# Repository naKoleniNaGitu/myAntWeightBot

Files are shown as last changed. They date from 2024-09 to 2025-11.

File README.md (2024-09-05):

# myAntWeightBot

## Sources

### Controler 
I decided to go with ESP32-S3 develoment module for control flexibility and BT connectivity.

* [waveshare.com product esp32-s3-zero.htm](https://www.waveshare.com/product/mcu-tools/development-boards/esp32/esp32-s3-zero.htm)
* [ESP32 S3 zero wiki](https://www.waveshare.com/wiki/ESP32-S3-Zero)

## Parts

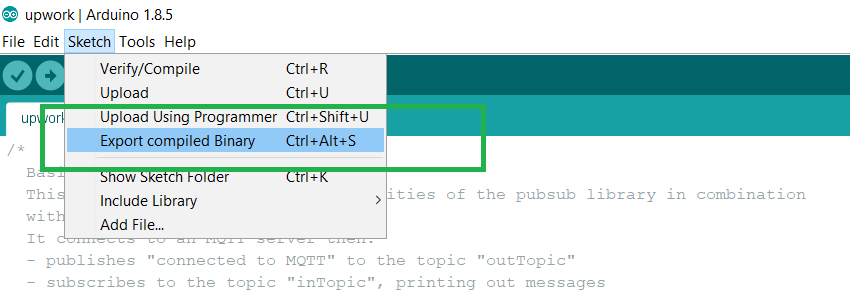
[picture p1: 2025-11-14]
platformio_projects/myAntWeightBot_v3/components/arduino/docs/_static/ota_export_to_binary.png

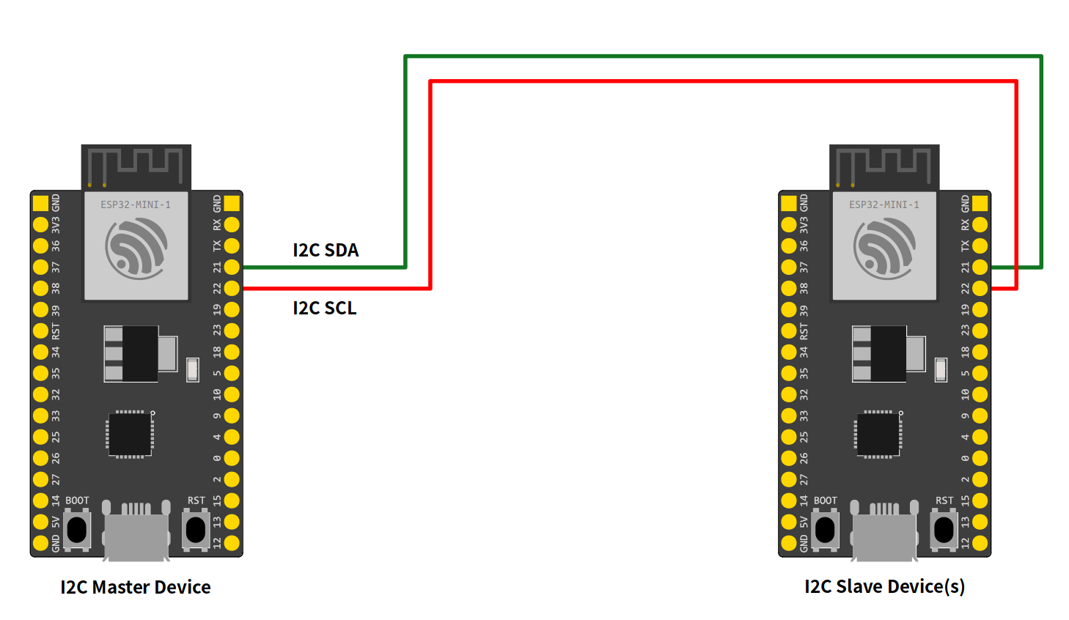
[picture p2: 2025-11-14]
platformio_projects/myAntWeightBot_v3/components/arduino/docs/_static/arduino_i2c_slave.png

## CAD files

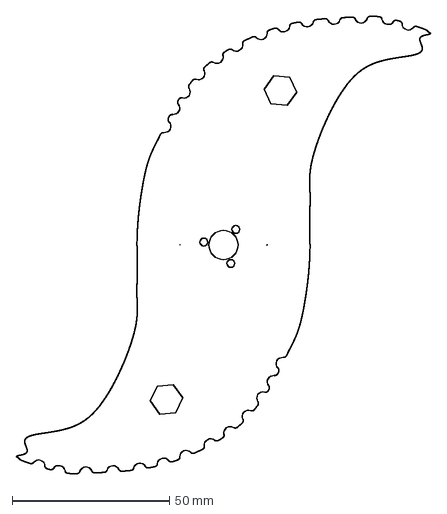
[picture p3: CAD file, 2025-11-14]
CNC blade.dxf
131.6 x 145.4 mm

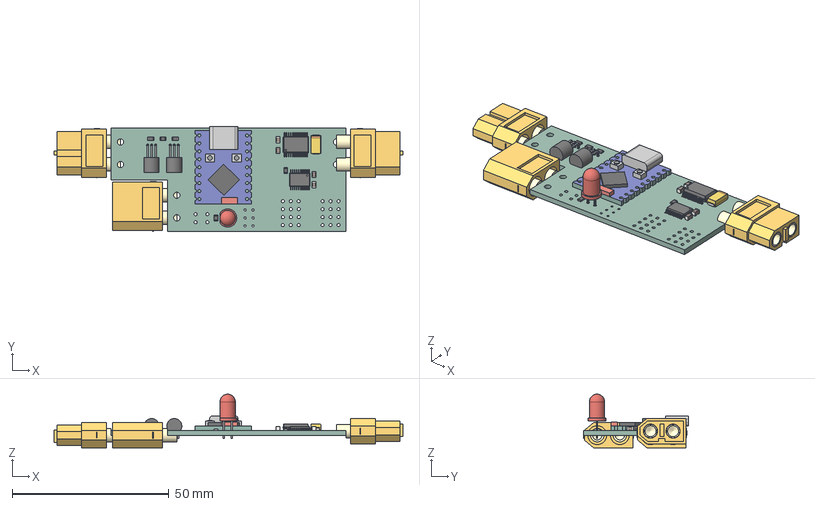
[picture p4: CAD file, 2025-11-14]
HW design/myAntWeightBot/myAntWeightBot.step
111.4 x 33.6 x 17.2 mm
R_0805_2012Metric x 5
LED_D5.0mm
AMASS_XT60-F_1x02_P7.2mm_Vertical v2 x 2
CP_EIA_6032_20_AVX_F
C_0805_2012Metric x 4
TO-92_Inline_W4.0mm_Horizontal_FlatSideDown x 2
TSSOP_20_44x65mm_P065mm
ESP32-S3-Zero v2
SSOP_24_53x82mm_P065mm
AMASS_XT60-M_1x02_P7.2mm_Vertical v2
myAntWeightBot_PCB

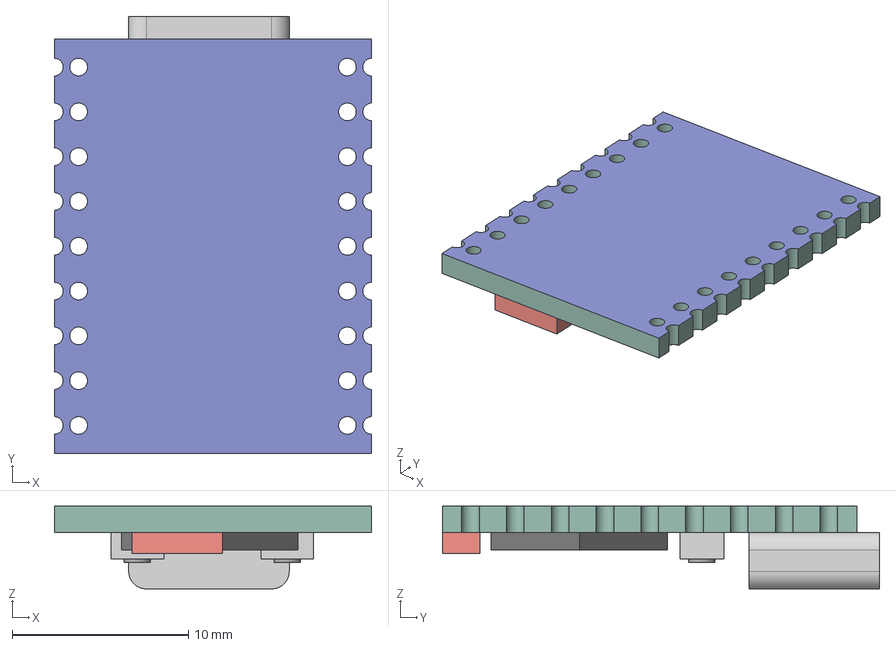
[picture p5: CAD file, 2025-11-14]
STL/ESP32-S3-Zero v2.step
18.0 x 24.8 x 4.70 mm

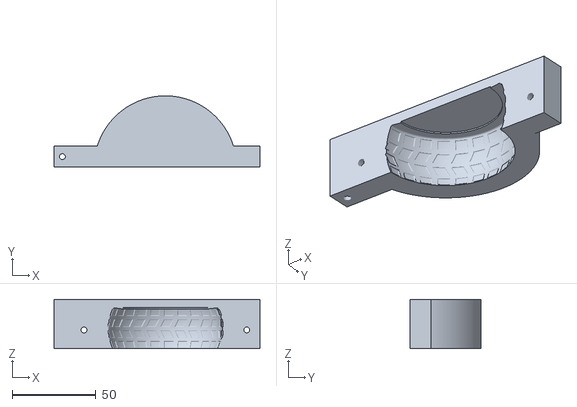
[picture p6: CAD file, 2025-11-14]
STL/wheel mold/wheel mold v1 - side L.stl
122.8 x 42.5 x 29.5

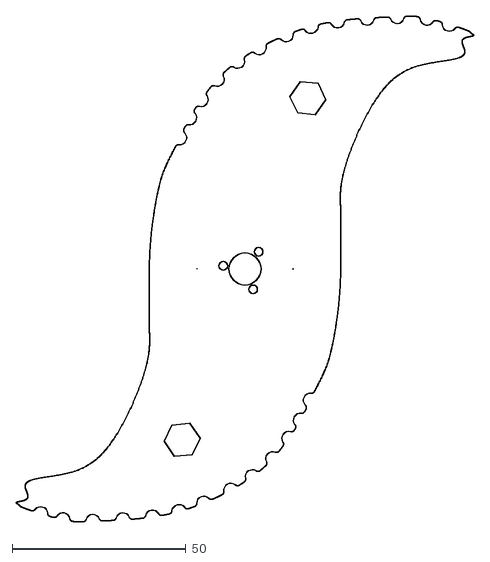
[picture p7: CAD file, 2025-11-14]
CNC blade v10.dxf
131.6 x 145.4

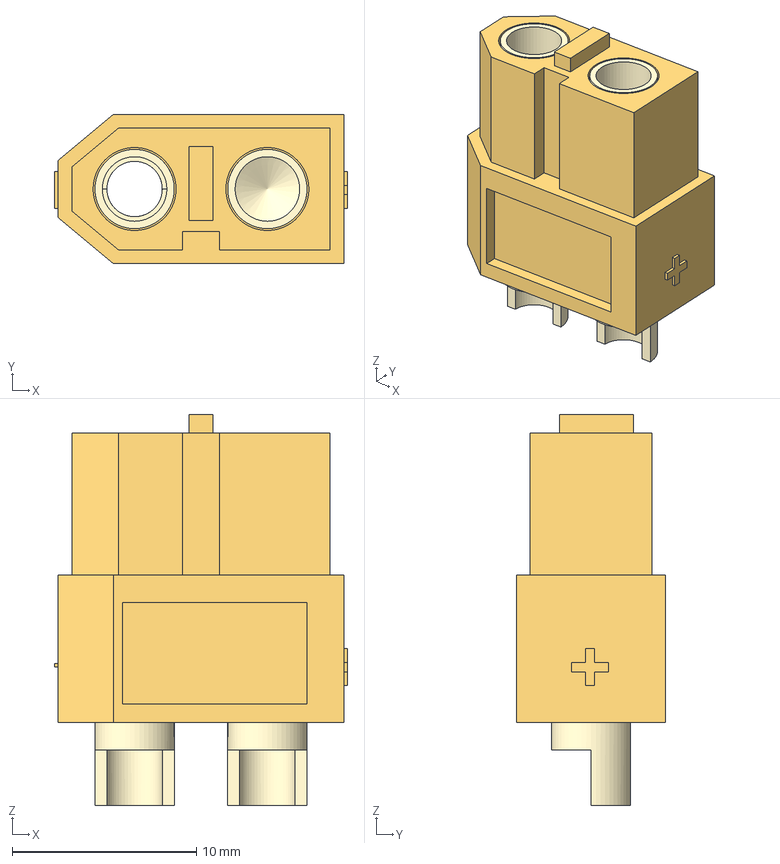
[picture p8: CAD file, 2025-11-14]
STL/AMASS_XT60-F_1x02_P7.2mm_Vertical v2.step
15.9 x 8.10 x 21.2 mm

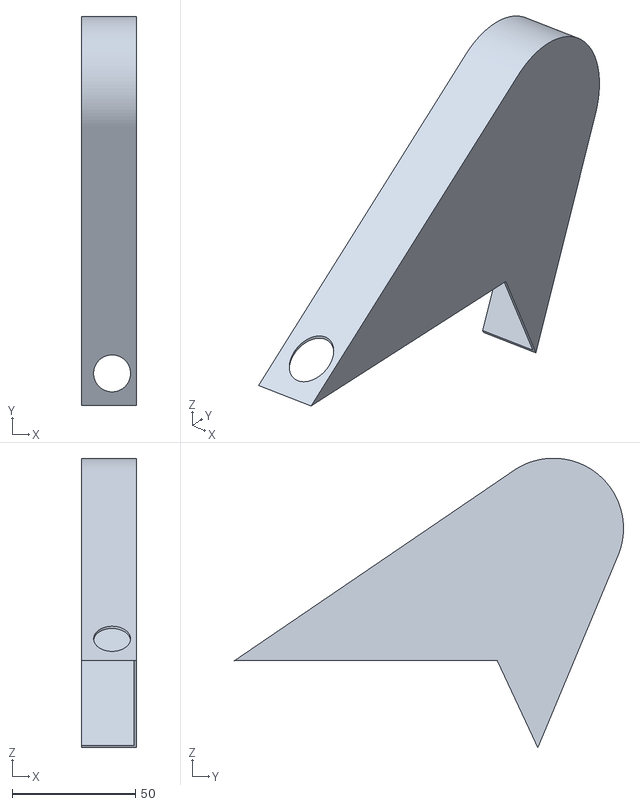
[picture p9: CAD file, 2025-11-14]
STL/insert right v 27.stl
22.5 x 158.0 x 117.6

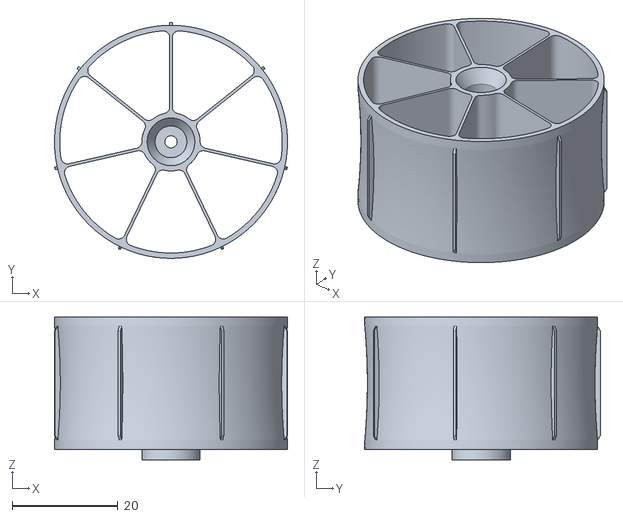
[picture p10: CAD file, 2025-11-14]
STL/strawberryBot & ufoBot/Wheel D50x25 v10.stl
44.0 x 44.5 x 27.0

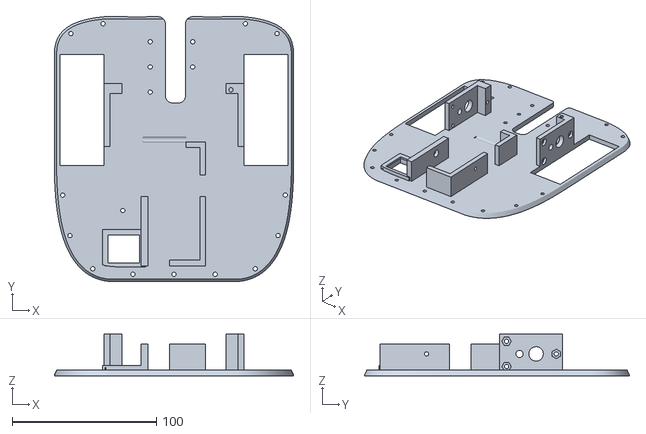
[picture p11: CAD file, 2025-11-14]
STL/BasePlate v28.stl
166.1 x 183.9 x 29.0

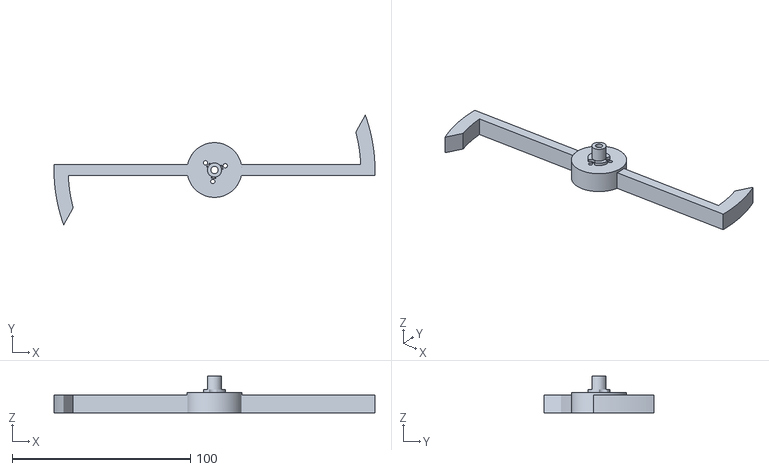
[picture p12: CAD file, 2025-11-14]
STL/strawberryBot & ufoBot/strawberryWeapon v3.stl
180.0 x 61.6 x 20.5

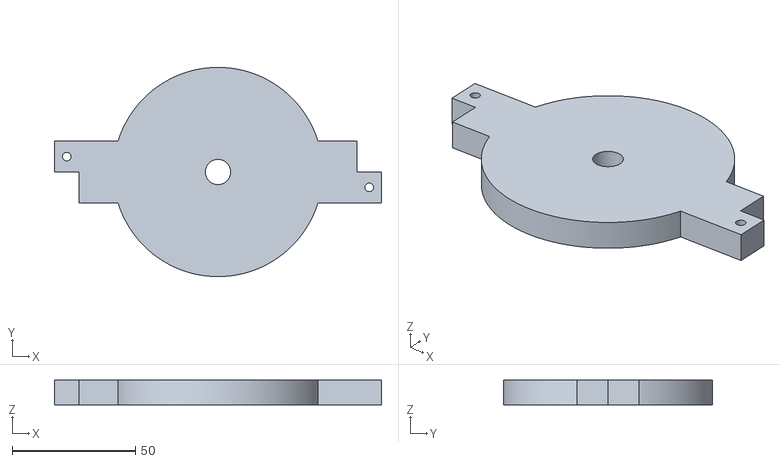
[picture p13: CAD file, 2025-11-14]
STL/wheel mold/wheel mold v3 - lid.stl
132.8 x 85.0 x 10.0

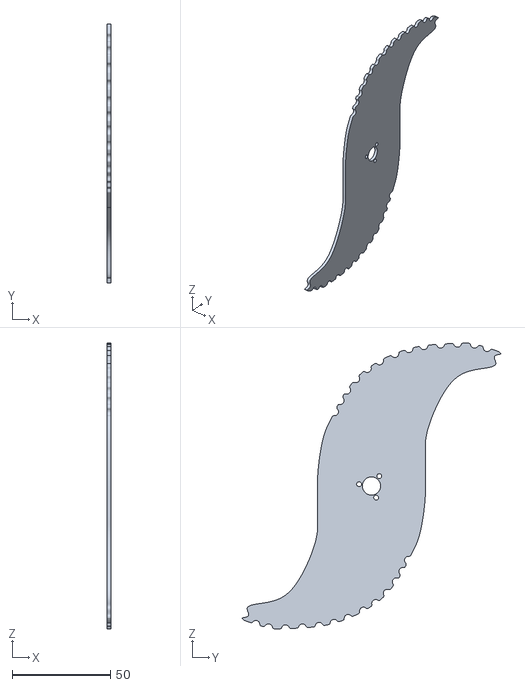
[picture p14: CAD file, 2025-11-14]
STL/blade v15.stl
2.00 x 131.6 x 145.4

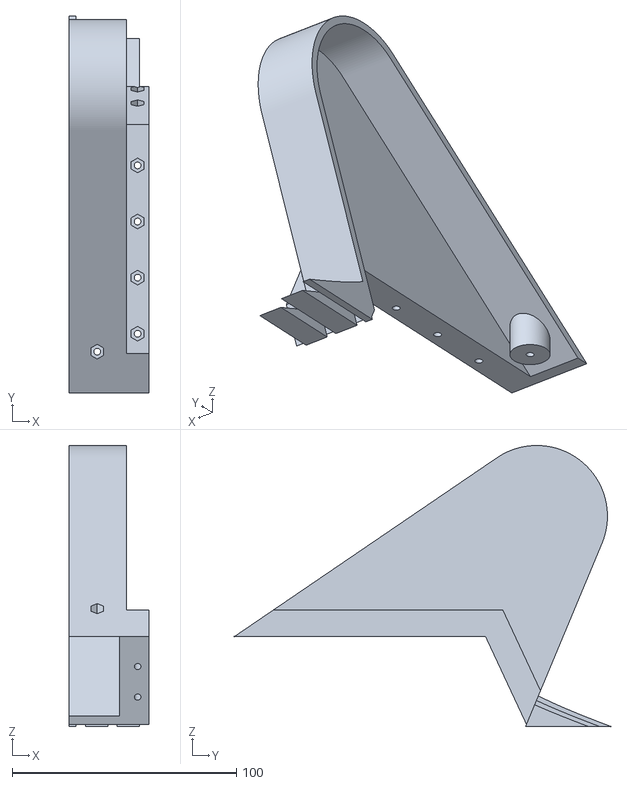
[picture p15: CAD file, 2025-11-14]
STL/ArmCover v 25.stl
35.5 x 167.9 x 125.2

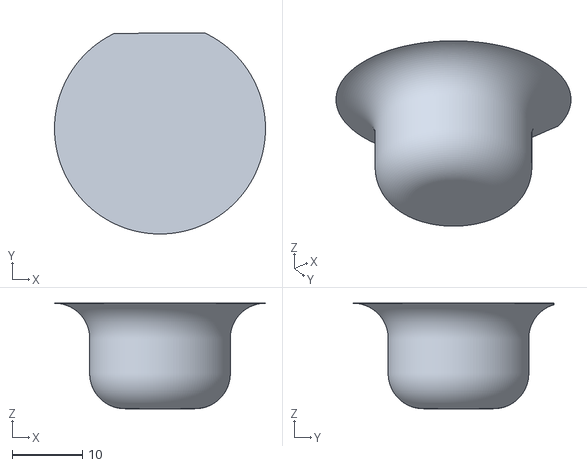
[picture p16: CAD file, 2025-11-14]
STL/SlidingPad 2 v15.stl
30.0 x 28.6 x 15.0

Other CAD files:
STL/wheel mold/wheel mold v1 - side R.stl
STL/BearingHolder v21.stl
STL/SlidingPad 3 v15.stl
STL/BasePlate.stl
CNC blade.dwg
STL/AMASS_XT60-M_1x02_P7.2mm_Vertical v2.step
STL/ArmCover Left v29.stl
STL/ArmCover Right v29.stl
STL/Armor v29.stl
STL/Armor v32.stl
STL/BasePlate v11.stl
STL/BasePlate v13.stl
STL/BasePlate v15.stl
STL/BladeHolder v11.stl
STL/BladeHolder v15.stl
STL/Shell v30.stl
STL/Shell v31.stl
STL/Shim v31.stl
STL/SlidingPad 1 v11.stl
STL/SlidingPad 1 v15.stl
STL/SlidingPad 2 v11.stl
STL/SlidingPad 3 v11.stl
STL/blade v11.stl
STL/strawberryBot & ufoBot/Wheel D50x25 v7.stl
STL/strawberryBot & ufoBot/Wheel D50x25 v8.stl
STL/strawberryBot & ufoBot/strawberryWeapon v2.stl
STL/wheel mold/wheel mold v1 - lid.stl

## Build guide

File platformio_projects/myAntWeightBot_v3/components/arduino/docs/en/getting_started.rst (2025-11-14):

###############
Getting Started
###############

About Arduino ESP32
-------------------

Welcome to the Arduino ESP32 support documentation! Here you will find important information on how to use the project.

First Things First
------------------

.. note::
    Before continuing, we must be clear that this project is supported by `Espressif Systems`_ and the community.
    Everyone is more than welcome to contribute back to this project.

ESP32 is a single 2.4 GHz Wi-Fi-and-Bluetooth SoC (System On a Chip) designed by `Espressif Systems`_.

ESP32 is designed for mobile, wearable electronics, and Internet-of-Things (IoT) applications. It features all the state-of-the-art characteristics
of low-power chips, including fine-grained clock gating, multiple power modes,and dynamic power scaling. For instance, in a low-power IoT sensor
hub application scenario, ESP32 is woken-up periodically and only when a specified condition is detected. Low-duty cycle is used to minimize the
amount of energy that the chip expends.

The output of the power amplifier is also adjustable, thus contributing to an optimal trade-off between communication range, data rate and
power consumption.

The ESP32 series is available as a chip or module.

.. _supported_socs:

Supported SoC's
---------------

Here are the ESP32 series supported by the Arduino-ESP32 project:

========== ====== =========== =================================
SoC        Stable Development Datasheet
========== ====== =========== =================================
ESP32      Yes    Yes         `ESP32`_
ESP32-C3   Yes    Yes         `ESP32-C3`_
ESP32-C6   Yes    Yes         `ESP32-C6`_
ESP32-H2   Yes    Yes         `ESP32-H2`_
ESP32-P4   Yes    Yes         `ESP32-P4`_
ESP32-S2   Yes    Yes         `ESP32-S2`_
ESP32-S3   Yes    Yes         `ESP32-S3`_
========== ====== =========== =================================

.. note::
    ESP32-C2 is also supported by Arduino-ESP32 but requires using Arduino as an ESP-IDF component or rebuilding the static libraries.
    For more information, see the `Arduino as an ESP-IDF component documentation <esp-idf_component.html>`_ or the
    `Lib Builder documentation <lib_builder.html>`_, respectively.

See `Boards <boards/boards.html>`_ for more details about ESP32 development boards.

Arduino Core Reference
----------------------

This documentation is built on the ESP32 and we are not going to cover the common Arduino API. To see the Arduino reference documentation,
please consider reading the official documentation.

Arduino Official Documentation: `Arduino Reference`_.

Supported Operating Systems
---------------------------

+-------------------+-------------------+-------------------+
|     |       |       |
+-------------------+-------------------+-------------------+
| Windows           | Linux             | macOS             |
+-------------------+-------------------+-------------------+





Supported IDEs
---------------------------

Here is the list of supported IDE for Arduino ESP32 support integration.

+-------------------+
|     |
+-------------------+
| Arduino IDE       |
+-------------------+



See `Installing Guides <installing.html>`_ for more details on how to install the Arduino ESP32 support.

Support
-------

This is an open project and it's supported by the community. Fell free to ask for help in one of the community channels.

Community
---------

The Arduino community is huge! You can find a lot of useful content on the Internet.
Here are some community channels where you may find information and ask for some help, if needed.

- `ESP32 Forum`_: Official Espressif Forum.
- `ESP32 Forum - Arduino`_: Official Espressif Forum for Arduino related discussions.
- `ESP32 Forum - Hardware`_: Official Espressif Forum for Hardware related discussions.
- `Espressif Developer Portal`_: Official Espressif Developer Portal with tutorials, examples, workshops, and more.
- `Arduino Core for Espressif (Discord)`_: Official Espressif Discord channel for the Arduino Core.
- `Espressif MCUs (Discord)`_
- `ESP32 on Reddit`_

Issues Reporting
----------------

Before opening a new issue, please read this:

Be sure to search for a similar reported issue. This avoids duplicating or creating noise in the GitHub Issues reporting.
We also have the troubleshooting guide to save your time on the most common issues reported by users.

For more details about creating new Issue, see the `Issue Template <https://github.com/espressif/arduino-esp32/blob/master/.github/ISSUE_TEMPLATE/Issue-report.yml>`_.

If you have any new idea, see the `Feature request Template <https://github.com/espressif/arduino-esp32/blob/master/.github/ISSUE_TEMPLATE/Feature-request.yml>`_.

First Steps
-----------

Here are the first steps to get the Arduino ESP32 support running.

To install Arduino-ESP32, please see the dedicated section on the Installation guide. We recommend you install it using the boards manager.

.. toctree::
    :maxdepth: 2

    How to Install <installing>
    Development Boards <boards/boards>

Examples
--------

After installing the toolchain into your environment, you will be able to see all the dedicated examples for the ESP32. These examples are located
in the examples menu or inside each library folder.

    https://github.com/espressif/arduino-esp32/tree/master/libraries

There is also a `list of examples <https://techtutorialsx.com/category/esp32/>`_ managed outside of Espressif, so check them out.

.. include:: common/datasheet.inc

Resources
---------

.. _Espressif Systems: https://www.espressif.com
.. _Espressif Product Selector: https://products.espressif.com/
.. _Espressif Developer Portal: https://developer.espressif.com/
.. _Arduino.cc: https://www.arduino.cc/en/Main/Software
.. _Arduino Reference: https://www.arduino.cc/reference/en/
.. _ESP32 Forum: https://esp32.com
.. _ESP32 Forum - Arduino: https://esp32.com/viewforum.php?f=19
.. _ESP32 Forum - Hardware: https://esp32.com/viewforum.php?f=12
.. _Arduino Core for Espressif (Discord): https://discord.gg/8xY6e9crwv
.. _Adafruit (Discord): https://discord.gg/adafruit
.. _Espressif MCUs (Discord): https://discord.com/invite/XqnZPbF
.. _ESP32 on Reddit: https://www.reddit.com/r/esp32

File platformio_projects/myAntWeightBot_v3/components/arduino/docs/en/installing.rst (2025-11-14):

##########
Installing
##########

This guide will show how to install the Arduino-ESP32 support.

Before Installing
-----------------

We recommend you install the support using your favorite IDE, but other options are available depending on your operating system.
To install Arduino-ESP32 support, you can use one of the following options.

.. note::
   Users in China might have troubles with connection and download speeds using GitHub. Please use our Jihulab mirror as the repository source:

   ``https://jihulab.com/esp-mirror/espressif/arduino-esp32.git``

Installing using Arduino IDE
----------------------------



This is the way to install Arduino-ESP32 directly from the Arduino IDE.

.. note::
   For overview of SoC's support, take a look on `Supported Soc's table <https://docs.espressif.com/projects/arduino-esp32/en/latest/getting_started.html#supported-soc-s>`_ where you can find if the particular chip is under stable or development release.

- Stable release link::

   https://espressif.github.io/arduino-esp32/package_esp32_index.json

- Development release link::

   https://espressif.github.io/arduino-esp32/package_esp32_dev_index.json

Users in China might have troubles with connection and download speeds using the links above. Please use our Jihulab mirror:

- Stable release link::

   https://jihulab.com/esp-mirror/espressif/arduino-esp32/-/raw/gh-pages/package_esp32_index_cn.json

- Development release link::

   https://jihulab.com/esp-mirror/espressif/arduino-esp32/-/raw/gh-pages/package_esp32_dev_index_cn.json

.. note::
   Starting with the Arduino IDE version 1.6.4, Arduino allows installation of third-party platform
   packages using Boards Manager. We have packages available for Windows, macOS, and Linux.

To start the installation process using the Boards Manager, follow these steps:

-  Install the current upstream Arduino IDE at the 1.8 level or later. The current version is at the `arduino.cc`_ website.

-  Start Arduino and open the Preferences window.



-  Enter one of the release links above into *Additional Board Manager URLs* field. You can add multiple URLs, separating them with commas.



-  Open Boards Manager from Tools > Board menu and install *esp32* platform (and do not forget to select your ESP32 board from Tools > Board menu after installation).
   Users in China must select the package version with the "-cn" suffix and perform updates manually.
   Automatic updates are not supported in this region, as they target the default package without the "-cn" suffix, resulting in download failures.



- Restart Arduino IDE.

Windows (manual installation)
-----------------------------

.. warning:: Arduino ESP32 core v2.x.x cannot be used on Windows 8.x x86 (32 bits), Windows 7 or earlier. The Windows 32 bits OS is no longer supported by this toolchain.

   The Arduino ESP32 v1.0.6 still works on WIN32. You might want to install python 3.8.x because it is the latest release supported by Windows 7.

Steps to install Arduino ESP32 support on Windows:

**Step 1**

1. Download and install the latest Arduino IDE ``Windows Installer`` from [arduino.cc](https://www.arduino.cc/en/Main/Software)
2. Download and install Git from [git-scm.com](https://git-scm.com/download/win)
3. Start ``Git GUI`` and do the following steps:

- Select ``Clone Existing Repository``



- Select source and destination
   - Sketchbook Directory: Usually ``C:/Users/[YOUR_USER_NAME]/Documents/Arduino`` and is listed underneath the "Sketchbook location" in Arduino preferences.
   - Source Location: ``https://github.com/espressif/arduino-esp32.git``
   - Target Directory: ``[ARDUINO_SKETCHBOOK_DIR]/hardware/espressif/esp32``
   - Click ``Clone`` to start cloning the repository

**Step 2**



**Step 3**



- open a `Git Bash` session pointing to ``[ARDUINO_SKETCHBOOK_DIR]/hardware/espressif/esp32`` and execute ```git submodule update --init --recursive```
- Open ``[ARDUINO_SKETCHBOOK_DIR]/hardware/espressif/esp32/tools`` and double-click ``get.exe``

**Step 4**



- When ```get.exe``` finishes, you should see the following files in the directory

**Step 5**



1. Plug your ESP32 board and wait for the drivers to install (or install manually any that might be required)
2. Start Arduino IDE
3. Select your board in ``Tools > Board`` menu
4. Select the COM port that the board is attached to
5. Compile and upload (You might need to hold the boot button while uploading)



How to update to the latest code
********************************

1. Start ``Git GUI`` and you should see the repository under ``Open Recent Repository``. Click on it!



1. From menu ``Remote`` select ``Fetch from`` > ``origin``



1. Wait for git to pull any changes and close ``Git GUI``
2. Open ``[ARDUINO_SKETCHBOOK_DIR]/hardware/espressif/esp32/tools`` and double-click ``get.exe``



Linux
-----



Debian/Ubuntu
*************

- Install latest Arduino IDE from `arduino.cc`_.

- Open Terminal and execute the following command (copy -> paste and hit enter):

.. code-block:: bash

   sudo usermod -a -G dialout $USER && \
   sudo apt-get install git && \
   wget https://bootstrap.pypa.io/get-pip.py && \
   sudo python3 get-pip.py && \
   sudo pip3 install pyserial && \
   mkdir -p ~/Arduino/hardware/espressif && \
   cd ~/Arduino/hardware/espressif && \
   git clone https://github.com/espressif/arduino-esp32.git esp32 && \
   cd esp32/tools && \
   python3 get.py

- Restart Arduino IDE.

- If you have Arduino installed to ~/, modify the installation as follows, beginning at `mkdir -p ~/Arduino/hardware`:

.. code-block:: bash

   cd ~/Arduino/hardware
   mkdir -p espressif && \
   cd espressif && \
   git clone https://github.com/espressif/arduino-esp32.git esp32 && \
   cd esp32/tools && \
   python3 get.py

Fedora
******

- Install the latest Arduino IDE from `arduino.cc`_.

.. note::
   Command ``$ sudo dnf -y install arduino`` will most likely install an older release.

- Open Terminal and execute the following command (copy -> paste and hit enter):

.. code-block:: bash

   sudo usermod -a -G dialout $USER && \
   sudo dnf install git python3-pip python3-pyserial && \
   mkdir -p ~/Arduino/hardware/espressif && \
   cd ~/Arduino/hardware/espressif && \
   git clone https://github.com/espressif/arduino-esp32.git esp32 && \
   cd esp32/tools && \
   python get.py

- Restart Arduino IDE.

openSUSE
********

- Install the latest Arduino IDE from `arduino.cc`_.

- Open Terminal and execute the following command (copy -> paste and hit enter):

.. code-block:: bash

   sudo usermod -a -G dialout $USER && \
   if [ `python --version 2>&1 | grep '2.7' | wc -l` = "1" ]; then \
   sudo zypper install git python-pip python-pyserial; \
   else \
   sudo zypper install git python3-pip python3-pyserial; \
   fi && \
   mkdir -p ~/Arduino/hardware/espressif && \
   cd ~/Arduino/hardware/espressif && \
   git clone https://github.com/espressif/arduino-esp32.git esp32 && \
   cd esp32/tools && \
   python get.py

- Restart Arduino IDE.

macOS
-----

- Install the latest Arduino IDE from `arduino.cc`_.

- Open Terminal and execute the following command (copy -> paste and hit enter):

.. code-block:: bash

   mkdir -p ~/Documents/Arduino/hardware/espressif && \
   cd ~/Documents/Arduino/hardware/espressif && \
   git clone https://github.com/espressif/arduino-esp32.git esp32 && \
   cd esp32/tools && \
   python get.py

Where ``~/Documents/Arduino`` represents your sketch book location as per "Arduino" > "Preferences" > "Sketchbook location" (in the IDE once started). Adjust the command above accordingly.

- If you get the error below, install through the command line dev tools with `xcode-select --install` and try the command above again:

.. code-block:: bash

   xcrun: error: invalid active developer path (/Library/Developer/CommandLineTools), missing xcrun at: /Library/Developer/CommandLineTools/usr/bin/xcrun

- Run the command:

.. code-block:: bash

   xcode-select --install

- Try ``python3`` instead of ``python`` if you get the error: ``IOError: [Errno socket error] [SSL: TLSV1_ALERT_PROTOCOL_VERSION] tlsv1 alert protocol version (_ssl.c:590)`` when running ``python get.py``

- If you get the following error when running ``python get.py``: ``urllib.error.URLError: <urlopen error SSL: CERTIFICATE_VERIFY_FAILED``, go to ``Macintosh HD > Applications > Python3.6 folder (or any other python version)``, and run the following scripts: Install Certificates.command and Update Shell Profile.command

- Restart Arduino IDE.

.. _Arduino.cc: https://www.arduino.cc/en/Main/Software

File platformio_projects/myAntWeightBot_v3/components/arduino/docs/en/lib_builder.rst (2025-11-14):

###############
Library Builder
###############

About
-----

Espressif provides a macOS and Linux `tool <https://github.com/espressif/esp32-arduino-lib-builder>`_ to simplify building your own compiled libraries for use in Arduino IDE (or your favorite IDE).

This tool can be used to change the project or a specific configuration according to your needs.

Installing
----------

To install the Library Builder into your environment, please, follow the instructions below.

- Clone the ESP32 Arduino lib builder:

.. code-block:: bash

    git clone https://github.com/espressif/esp32-arduino-lib-builder

- Go to the ``esp32-arduino-lib-builder`` folder:

.. code-block:: bash

    cd esp32-arduino-lib-builder

- Build:

.. code-block:: bash

    ./build.sh

If everything works, you may see the following message: ``Successfully created esp32 image.``

Dependencies
************

To build the library you will need to install some dependencies. Maybe you already have installed it, but it is a good idea to check before building.

- Install all dependencies (**Ubuntu**):

.. code-block:: bash

    sudo apt-get install git wget curl libssl-dev libncurses-dev flex bison gperf cmake ninja-build ccache jq

- Install Python and upgrade pip:

.. code-block:: bash

    sudo apt-get install python3
    sudo pip install --upgrade pip

- Install all required packages:

.. code-block:: bash

    pip install --user setuptools pyserial click cryptography future pyparsing pyelftools

Building
--------

If you have all the dependencies met, it is time to build the libraries.

To build using the default configuration:

.. code-block:: bash

    ./build.sh

Custom Build
************

There are some options to help you create custom libraries. You can use the following options:

Usage
^^^^^

.. code-block:: bash

    build.sh [-s] [-A arduino_branch] [-I idf_branch] [-i idf_commit] [-c path] [-t <target>] [-b <build|menuconfig|idf_libs|copy_bootloader|mem_variant>] [config ...]

Skip Install/Update
^^^^^^^^^^^^^^^^^^^

Skip installing/updating of ESP-IDF and all components

.. code-block:: bash

    ./build.sh -s

This option can be used if you already have the ESP-IDF and all components already in your environment.

Set Arduino-ESP32 Branch
^^^^^^^^^^^^^^^^^^^^^^^^

Set which branch of arduino-esp32 to be used for compilation

.. code-block:: bash

    ./build.sh -A <arduino_branch>

Set ESP-IDF Branch
^^^^^^^^^^^^^^^^^^

Set which branch of ESP-IDF is to be used for compilation

.. code-block:: bash

    ./build.sh -I <idf_branch>

Set the ESP-IDF Commit
^^^^^^^^^^^^^^^^^^^^^^

Set which commit of ESP-IDF to be used for compilation

.. code-block:: bash

    ./build.sh -i <idf_commit>

Deploy
^^^^^^

Deploy the build to github arduino-esp32

.. code-block:: bash

    ./build.sh -d

Set the Arduino-ESP32 Destination Folder
^^^^^^^^^^^^^^^^^^^^^^^^^^^^^^^^^^^^^^^^

Set the arduino-esp32 folder to copy the result to. ex. '$HOME/Arduino/hardware/espressif/esp32'

.. code-block:: bash

    ./build.sh -c <path>

This function is used to copy the compiled libraries to the Arduino folder.

Set the Target
^^^^^^^^^^^^^^

Set the build target(chip). ex. 'esp32s3'

.. code-block:: bash

    ./build.sh -t <target>

This build command will build for the ESP32-S3 target. You can specify other targets.

* esp32
* esp32c2
* esp32c3
* esp32c6
* esp32h2
* esp32p4
* esp32s2
* esp32s3

Set Build Type
^^^^^^^^^^^^^^

Set the build type. ex. 'build' to build the project and prepare for uploading to a board.

.. note:: This command depends on the ``-t`` argument.

.. code-block:: bash

    ./build.sh -t esp32 -b <build|menuconfig|idf_libs|copy_bootloader|mem_variant>

Additional Configuration
^^^^^^^^^^^^^^^^^^^^^^^^

Specify additional configs to be applied. ex. ``qio 80m`` to compile for QIO Flash at 80 MHz.

.. note:: This command requires the ``-b`` to work properly.

.. code-block:: bash

    ./build.sh -t esp32 -b idf_libs qio 80m

User Interface
--------------

Starting from ``arduino-esp32`` version 3.0.0 (IDF v5.1), there is also a terminal user interface that can be used
to configure the libraries to be compiled.

It allows the user to select the targets to compile, change the configuration options and compile the libraries.
It has mouse support and can be pre-configured using command line arguments.

For more information and troubleshooting, check `the documentation <https://github.com/espressif/esp32-arduino-lib-builder/blob/master/tools/config_editor/README.md>`_.

To use the terminal user interface, make sure to have ``python>=3.9``, all the previous dependencies and install the ``textual`` library:

.. code-block:: bash

    pip install --user textual

You can then run the UI using the following command:

.. code-block:: bash

    ./tools/config_editor/app.py

Pre-Configuring the UI
**********************

The UI can be pre-configured using command line arguments. The following arguments are available:

- ``-t, --target <target>``: Comma-separated list of targets to be compiled.
  Choose from: *all*, *esp32*, *esp32s2*, *esp32s3*, *esp32c2*, *esp32c3*, *esp32c6*, *esp32h2*. Default: all except *esp32c2*;
- ``--copy, --no-copy``: Enable/disable copying the compiled libraries to ``arduino-esp32``. Enabled by default;
- ``-c, --arduino-path <path>``: Path to ``arduino-esp32`` directory. Default: OS dependent;
- ``-A, --arduino-branch <branch>``: Branch of the ``arduino-esp32`` repository to be used. Default: set by the build script;
- ``-I, --idf-branch <branch>``: Branch of the ``ESP-IDF`` repository to be used. Default: set by the build script;
- ``-i, --idf-commit <commit>``: Commit of the ``ESP-IDF`` repository to be used. Default: set by the build script;
- ``-D, --debug-level <level>``: Debug level to be set in ``ESP-IDF``.
  Choose from: *default*, *none*, *error*, *warning*, *info*, *debug*, *verbose*. Default: *default*.

Please note that all these options can be changed in the UI itself and are only used for automation purposes.

Screens
*******

There are many screens in the UI that are used to configure the libraries to be compiled.
Note that in all screens you can also use the shortcut keys shown in the footer bar to navigate.

The UI consists of the following screens:

- **Main Menu**: The main screen shows buttons to navigate to the other screens.
- **Compile Screen**: The compile screen shows the output of the compilation process and any errors that may have occurred.
- **Sdkconfig Editor**: The sdkconfig editor screen is a simple text editor that shows you the sdkconfig files that will be used for compilation.
  You can edit the files here to customize the generated libraries.
- **Settings Screen**: The settings screen allows you to change the settings of the compilation process.
  Here you can change:

  - The targets that the libraries will be compiled for. To save time, you can compile the libraries only for the target you are using;
  - Whether the compiled libraries will be copied to the ``arduino-esp32`` directory after compilation so that they can be used in the Arduino IDE;
  - The path to the ``arduino-esp32`` directory. This will be automatically set if the ``arduino-esp32`` repository is in one of the default locations.
    If not, you can set it manually here. If using the docker image, it should not be changed as the mount point is fixed;
  - The branch of the ``arduino-esp32`` repository to be used. This is useful if you want to compile the libraries for a
    specific branch or pull request of the ``arduino-esp32`` repository. Leave empty to use the default branch for this ``ESP-IDF`` version;
  - The branch of the ``ESP-IDF`` repository to be used. This is useful if you want to compile the libraries for a specific branch of the ``ESP-IDF`` repository.
    Leave empty to use the default branch for this IDF version;
  - The commit of the ``ESP-IDF`` repository to be used. This is useful if you want to compile the libraries for a specific commit on the selected branch.
    Leave empty to use the latest commit;
  - The debug level to be set in ``ESP-IDF``.

Docker Image
------------

You can use a docker image for building the static libraries of ESP-IDF components for use in Arduino projects.
This image contains a copy of the ``esp32-arduino-lib-builder`` repository and already includes or will obtain all the required tools and dependencies to build the Arduino static libraries.

The current supported architectures by the Docker image are:

* ``amd64``
* ``arm64``

.. note::
    Building the libraries using the Docker image is much slower than building them natively on the host machine.
    It is recommended to use the Docker image only when the host machine does not meet the requirements for building the libraries (e.g., building on Windows).

Tags
****

Multiple tags of this image are maintained:

- ``latest``: tracks ``master`` branch of the Lib Builder. Note that the ``latest`` tag is not recommended for use as, depending on the
  development stage of the Lib Builder, it might not be stable or might not contain the latest changes;
- ``release-vX.Y``: tracks ``release/vX.Y`` branch of the Lib Builder.

.. note::
    Versions of Lib Builder released before this feature was introduced do not have corresponding Docker image versions.
    You can check the up-to-date list of available tags at https://hub.docker.com/r/espressif/esp32-arduino-lib-builder/tags.

Usage
*****

Before using the ``espressif/esp32-arduino-lib-builder`` Docker image locally, make sure you have Docker installed and running on your machine.
Follow the instructions at https://docs.docker.com/install/, if it is not installed yet.

If using the image in a CI environment, consult the documentation of your CI service on how to specify the image used for the build process.

Building the Libraries
^^^^^^^^^^^^^^^^^^^^^^

You have two options to run the Docker image to build the libraries. Manually or using the provided run script.

To run the Docker image manually, use the following command from the root of the ``arduino-esp32`` repository:

.. code-block:: bash
    :substitutions:

    docker run --rm -it -v $PWD:/arduino-esp32 -e TERM=xterm-256color espressif/esp32-arduino-lib-builder:release-v|idf_version|

This will start the Lib Builder UI for compiling the libraries. The above command explained:

- ``docker run``: Runs a command in a container;
- ``--rm``: Optional. Automatically removes the container when it exits. Remove this flag if you plan to use the container multiple times;
- ``-i`` Run the container in interactive mode;
- ``-t`` Allocate a pseudo-TTY;
- ``-e TERM=xterm-256color``: Optional. Sets the terminal type to ``xterm-256color`` to display colors correctly;
- ``-v $PWD:/arduino-esp32``: Optional. Mounts the current folder at ``/arduino-esp32`` inside the container. If not provided, the container will not copy the compiled libraries to the host machine;
- :substitution-code:`espressif/esp32-arduino-lib-builder:release-v|idf_version|`: uses Docker image ``espressif/esp32-arduino-lib-builder`` with tag :substitution-code:`release-v|idf_version|`.
  The ``latest`` tag is implicitly added by Docker when no tag is specified. It is recommended to use a specific version tag to ensure reproducibility of the build process.

.. warning::
    The ``-v`` option is used to mount a folder from the host machine to the container. Make sure the folder already exists on the host machine before running the command.
    Otherwise, the folder will be created with root permissions and files generated inside the container might cause permission issues and compilation errors.

.. note::
   When the mounted directory ``/arduino-esp32`` contains a git repository owned by a different user (``UID``) than the one running the Docker container,
   git commands executed within ``/arduino-esp32`` might fail, displaying an error message ``fatal: detected dubious ownership in repository at '/arduino-esp32'``.
   To resolve this issue, you can designate the ``/arduino-esp32`` directory as safe by setting the ``LIBBUILDER_GIT_SAFE_DIR`` environment variable during the Docker container startup.
   For instance, you can achieve this by including ``-e LIBBUILDER_GIT_SAFE_DIR='/arduino-esp32'`` as a parameter. Additionally, multiple directories can be specified by using a ``:`` separator.
   To entirely disable this git security check, ``*`` can be used.

After running the above command, you will be inside the container and the libraries can be built using the user interface.

By default the docker container will run the user interface script. If you want to run a specific command, you can pass it as an argument to the ``docker run`` command.
For example, to run a terminal inside the container, you can run:

.. code-block:: bash
    :substitutions:

    docker run -it espressif/esp32-arduino-lib-builder:release-v|idf_version| /bin/bash

Running the Docker image using the provided run script will depend on the host OS.
Use the following command from the root of the ``arduino-esp32`` repository to execute the image in a Linux or macOS environment for
the :substitution-code:`release-v|idf_version|` tag:

.. code-block:: bash
    :substitutions:

    curl -LJO https://raw.githubusercontent.com/espressif/esp32-arduino-lib-builder/refs/heads/release/v|idf_version|/tools/docker/run.sh
    chmod +x run.sh
    ./run.sh $PWD

For Windows, use the following command in PowerShell from the root of the ``arduino-esp32`` repository:

.. code-block:: powershell
    :substitutions:

    Invoke-WebRequest -Uri "https://raw.githubusercontent.com/espressif/esp32-arduino-lib-builder/refs/heads/release/v|idf_version|/tools/docker/run.ps1" -OutFile "run.ps1"
    .\run.ps1 $pwd

As the script is unsigned, you may need to change the execution policy of the current session before running the script.
To do so, run the following command in PowerShell:

.. code-block:: powershell

    Set-ExecutionPolicy -Scope Process -ExecutionPolicy Bypass

.. warning::
    It is always a good practice to understand what the script does before running it.
    Make sure to analyze the content of the script to ensure it is safe to run and won't cause any harm to your system.

Building Custom Images
**********************

To build a custom Docker image, you need to clone the Lib Builder repository and use the provided Dockerfile in the Lib Builder repository. The Dockerfile is located in the ``tools/docker`` directory.

The `Docker file in the Lib Builder repository <https://github.com/espressif/esp32-arduino-lib-builder/blob/master/tools/docker/Dockerfile>`_ provides several build arguments which can be used to customize the Docker image:

- ``LIBBUILDER_CLONE_URL``: URL of the repository to clone Lib Builder from. Can be set to a custom URL when working with a fork of Lib Builder. The default is ``https://github.com/espressif/esp32-arduino-lib-builder.git``;
- ``LIBBUILDER_CLONE_BRANCH_OR_TAG``: Name of a git branch or tag used when cloning Lib Builder. This value is passed to the ``git clone`` command using the ``--branch`` argument. The default is ``master``;
- ``LIBBUILDER_CHECKOUT_REF``: If this argument is set to a non-empty value, ``git checkout $LIBBUILDER_CHECKOUT_REF`` command performs after cloning. This argument can be set to the SHA of the specific commit to check out, for example, if some specific commit on a release branch is desired;
- ``LIBBUILDER_CLONE_SHALLOW``: If this argument is set to a non-empty value, ``--depth=1 --shallow-submodules`` arguments are used when performing ``git clone``. Depth can be customized using ``LIBBUILDER_CLONE_SHALLOW_DEPTH``. Doing a shallow clone significantly reduces the amount of data downloaded and the size of the resulting Docker image. However, if switching to a different branch in such a "shallow" repository is necessary, an additional ``git fetch origin <branch>`` command must be executed first;
- ``LIBBUILDER_CLONE_SHALLOW_DEPTH``: This argument specifies the depth value to use when doing a shallow clone. If not set, ``--depth=1`` will be used. This argument has effect only if ``LIBBUILDER_CLONE_SHALLOW`` is used. Use this argument if you are building a Docker image for a branch, and the image has to contain the latest tag on that branch. To determine the required depth, run ``git describe`` for the given branch and note the offset number. Increment it by 1, then use it as the value of this argument. The resulting image will contain the latest tag on the branch, and consequently ``git describe`` command inside the Docker image will work as expected;

To use these arguments, pass them via the ``--build-arg`` command line option. For example, the following command builds a Docker image with a shallow clone of Lib Builder from a specific repository and branch:

.. code-block:: bash

    docker buildx build -t lib-builder-custom:master \
        --build-arg LIBBUILDER_CLONE_BRANCH_OR_TAG=master \
        --build-arg LIBBUILDER_CLONE_SHALLOW=1 \
        --build-arg LIBBUILDER_CLONE_URL=https://github.com/espressif/esp32-arduino-lib-builder \
        tools/docker

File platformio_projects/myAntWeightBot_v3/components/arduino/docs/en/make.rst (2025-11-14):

==============
makeEspArduino
==============

The `makeEspArduino <https://github.com/plerup/makeEspArduino>`_ is a generic makefile for any ESP8266/ESP32 Arduino project.
Using it instead of the Arduino IDE makes it easier to do automated and production builds.

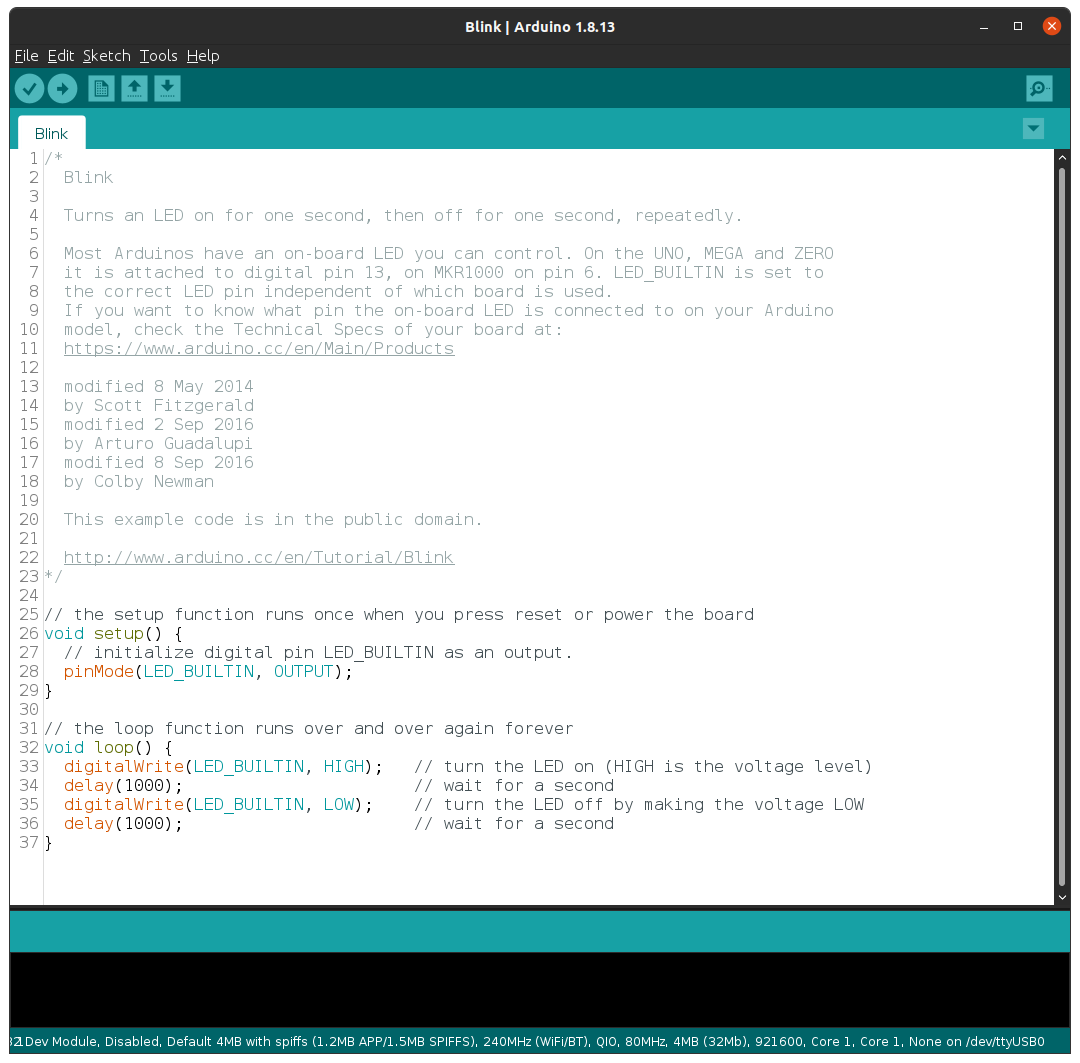
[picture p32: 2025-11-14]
platformio_projects/myAntWeightBot_v3/components/arduino/docs/_static/tutorials/basic/tutorial_basic_ide.png

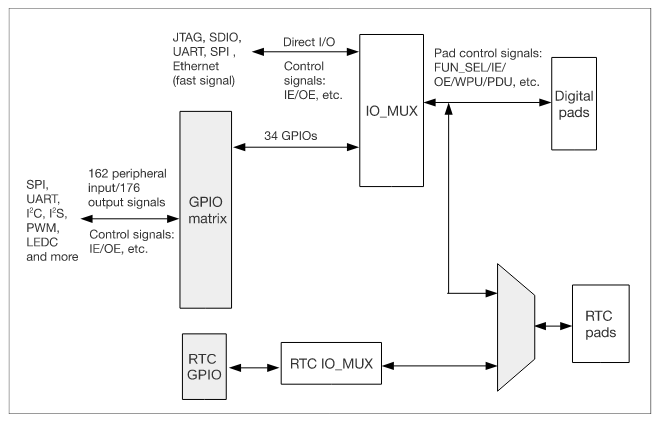
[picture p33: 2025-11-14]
platformio_projects/myAntWeightBot_v3/components/arduino/docs/_static/tutorials/peripherals/tutorial_peripheral_diagram.png

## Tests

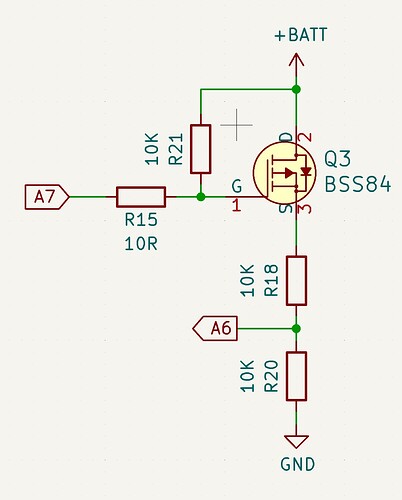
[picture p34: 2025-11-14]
voltage measurement high.jpeg

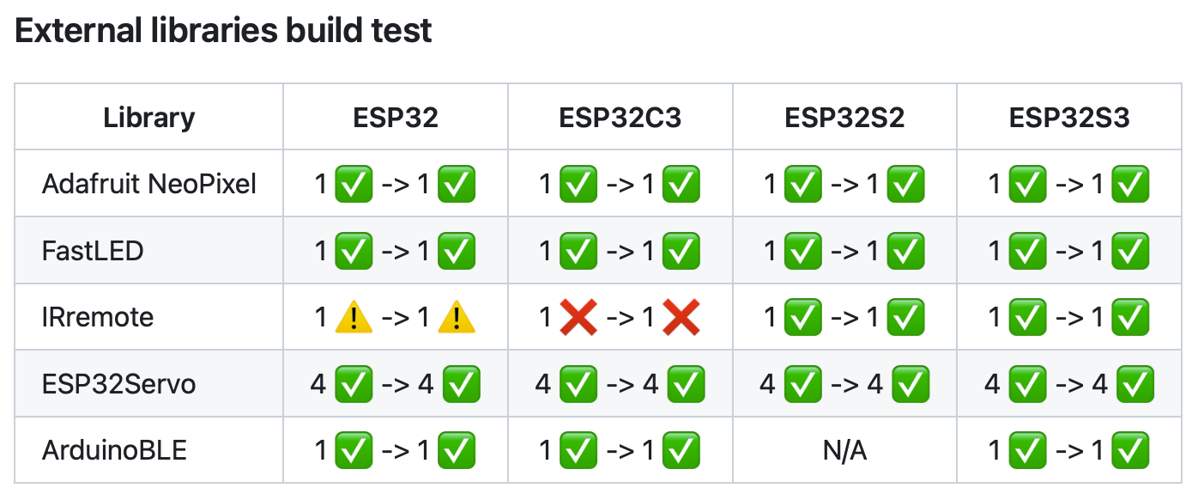
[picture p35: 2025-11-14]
platformio_projects/myAntWeightBot_v3/components/arduino/docs/_static/external_library_test_pr.png

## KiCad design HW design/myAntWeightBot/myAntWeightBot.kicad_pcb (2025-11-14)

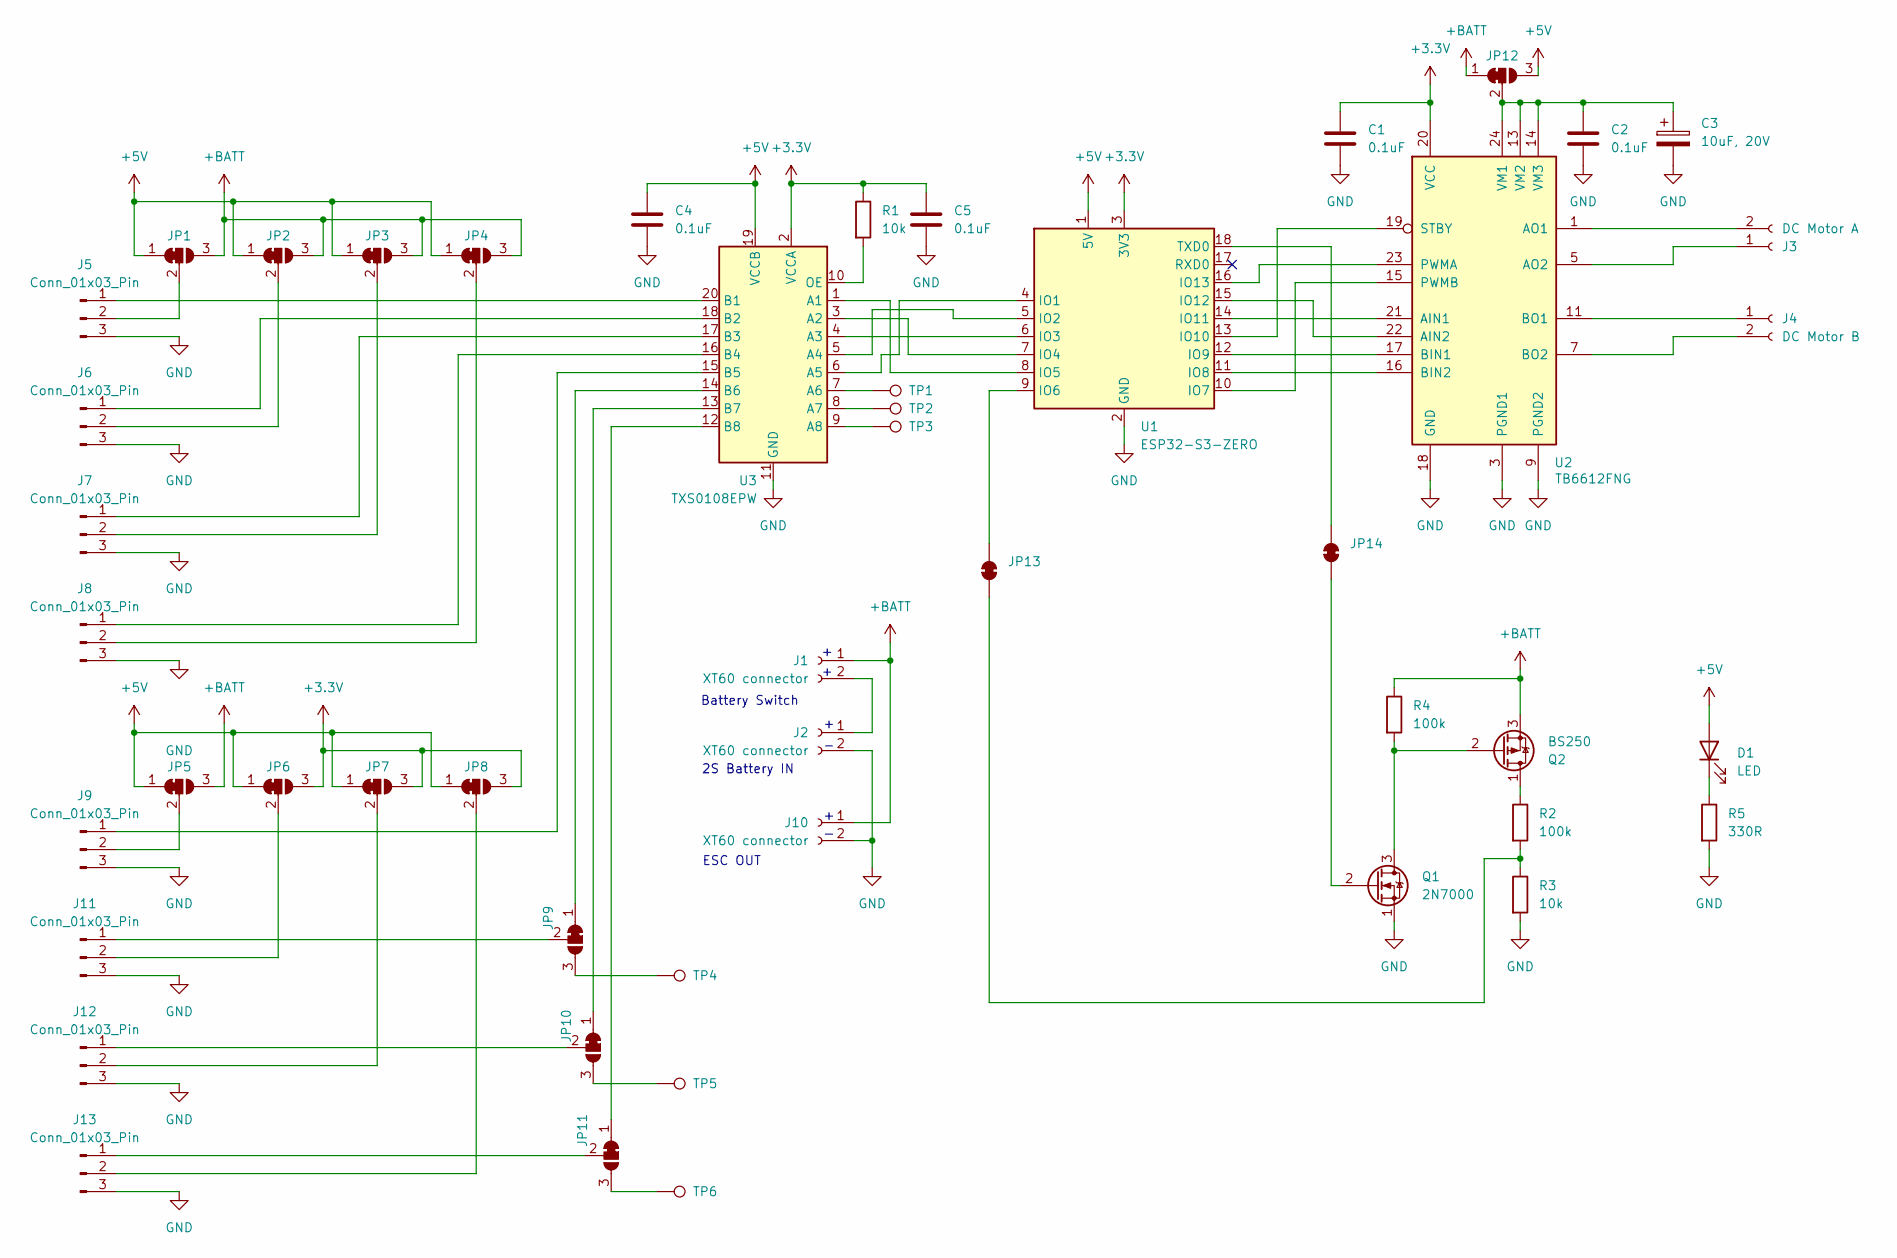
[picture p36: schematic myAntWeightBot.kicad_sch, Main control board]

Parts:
C1, C2, C4, C5: 0.1uF; C_0805_2012Metric
C3: 10uF, 20V; CP_EIA-6032-20_AVX-F
D1: LED; LED_D5.0mm
J1, J10: XT60 connector; XT60-F_1x02_P7.20mm_Horizontal_SMD
J2: XT60 connector; XT60-M_1x02_P7.20mm_Horizontal_SMD
J3: DC Motor A; PinHeader_1x02_P2.54mm_Vertical
J4: DC Motor B; PinHeader_1x02_P2.54mm_Vertical
J5, J6, J7, J8, J9, J11, J12, J13: Conn_01x03_Pin; PinHeader_1x03_P2.54mm_Vertical
JP1, JP2, JP3, JP4, JP5, JP6, JP7, JP8, JP9, JP10, JP11, JP12: SolderJumper_3_Bridged12; SolderJumper-3_P1.3mm_Bridged12_Pad1.0x1.5mm
JP13, JP14: SolderJumper_2_Bridged; SolderJumper-2_P1.3mm_Bridged_Pad1.0x1.5mm
Q1: 2N7000; TO-92_Inline_W4.0mm_Horizontal_FlatSideDown
Q2: BS250; TO-92_Inline_W4.0mm_Horizontal_FlatSideDown
R1, R3: 10k; R_0805_2012Metric
R2, R4: 100k; R_0805_2012Metric
R5: 330R; R_0805_2012Metric
TP1, TP2, TP3, TP4, TP5, TP6: TestPoint; TestPoint_THTPad_D1.5mm_Drill0.7mm
U1: ESP32-S3-ZERO
U2: TB6612FNG; SSOP-24_5.3x8.2mm_P0.65mm
U3: TXS0108EPW; TSSOP-20_4.4x6.5mm_P0.65mm

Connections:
+3.3V: C1.1, C5.1, JP6.3 (B), JP7.3 (B), JP8.3 (B), R1.1, U1.3 (3V3), U2.20 (VCC), U3.2 (VCCA)
+5V: C4.1, D1.2 (A), JP1.1 (A), JP2.1 (A), JP3.1 (A), JP4.1 (A), JP5.1 (A), JP6.1 (A), JP7.1 (A), JP8.1 (A), JP12.3 (B), U1.1 (5V), U3.19 (VCCB)
+BATT: J1.1, J10.1, JP1.3 (B), JP2.3 (B), JP3.3 (B), JP4.3 (B), JP5.3 (B), JP12.1 (A), Q2.3 (S), R4.1
GND: C1.2, C2.2, C3.2, C4.2, C5.2, J2.2, J5.3, J6.3, J7.3, J8.3, J9.3, J10.2, J11.3, J12.3, J13.3, Q1.1 (S), R3.2, R5.2, U1.2 (GND), U2.3 (PGND1), U2.4 (PGND1), U2.9 (PGND2), U2.10 (PGND2), U2.18 (GND), U3.11 (GND)
unnamed: D1.1 (K), R5.1
unnamed: J1.2, J2.1
unnamed: J3.1, U2.5 (AO2), U2.6 (AO2)
unnamed: J3.2, U2.1 (AO1), U2.2 (AO1)
unnamed: J4.1, U2.11 (BO1), U2.12 (BO1)
unnamed: J4.2, U2.7 (BO2), U2.8 (BO2)
unnamed: J5.1, U3.20 (B1)
unnamed: J5.2, JP1.2 (C)
unnamed: J6.1, U3.18 (B2)
unnamed: J6.2, JP2.2 (C)
unnamed: J7.1, U3.17 (B3)
unnamed: J7.2, JP3.2 (C)
unnamed: J8.1, U3.16 (B4)
unnamed: J8.2, JP4.2 (C)
unnamed: J9.1, U3.15 (B5)
unnamed: J9.2, JP5.2 (C)
unnamed: J11.1, JP9.2 (C)
unnamed: J11.2, JP6.2 (C)
unnamed: J12.1, JP10.2 (C)
unnamed: J12.2, JP7.2 (C)
unnamed: J13.1, JP11.2 (C)
unnamed: J13.2, JP8.2 (C)
unnamed: JP9.1 (A), U3.14 (B6)
unnamed: JP9.3 (B), TP4.1
unnamed: JP10.1 (A), U3.13 (B7)
unnamed: JP10.3 (B), TP5.1
unnamed: JP11.1 (A), U3.12 (B8)
unnamed: JP11.3 (B), TP6.1
unnamed: C2.1, C3.1, JP12.2 (C), U2.13 (VM2), U2.14 (VM3), U2.24 (VM1)
unnamed: JP13.1 (A), R2.2, R3.1
unnamed: JP13.2 (B), U1.9 (IO6)
unnamed: JP14.1 (A), Q1.2 (G)
unnamed: JP14.2 (B), U1.18 (TXD0)
unnamed: Q1.3 (D), Q2.2 (G), R4.2
unnamed: Q2.1 (D), R2.1
unnamed: U1.4 (IO1), U3.6 (A5)
unnamed: U1.5 (IO2), U3.5 (A4)
unnamed: U1.6 (IO3), U3.4 (A3)
unnamed: U1.7 (IO4), U3.3 (A2)
unnamed: U1.8 (IO5), U3.1 (A1)
unnamed: U1.10 (IO7), U2.15 (PWMB)
unnamed: U1.11 (IO8), U2.16 (BIN2)
unnamed: U1.12 (IO9), U2.17 (BIN1)
unnamed: U1.13 (IO10), U2.19 (STBY)
unnamed: U1.14 (IO11), U2.21 (AIN1)
unnamed: U1.15 (IO12), U2.22 (AIN2)
unnamed: U1.16 (IO13), U2.23 (PWMA)
unnamed: TP1.1, U3.7 (A6)
unnamed: TP2.1, U3.8 (A7)
unnamed: TP3.1, U3.9 (A8)
unnamed: R1.2, U3.10 (OE)

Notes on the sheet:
2S Battery IN
Battery Switch
ESC OUT

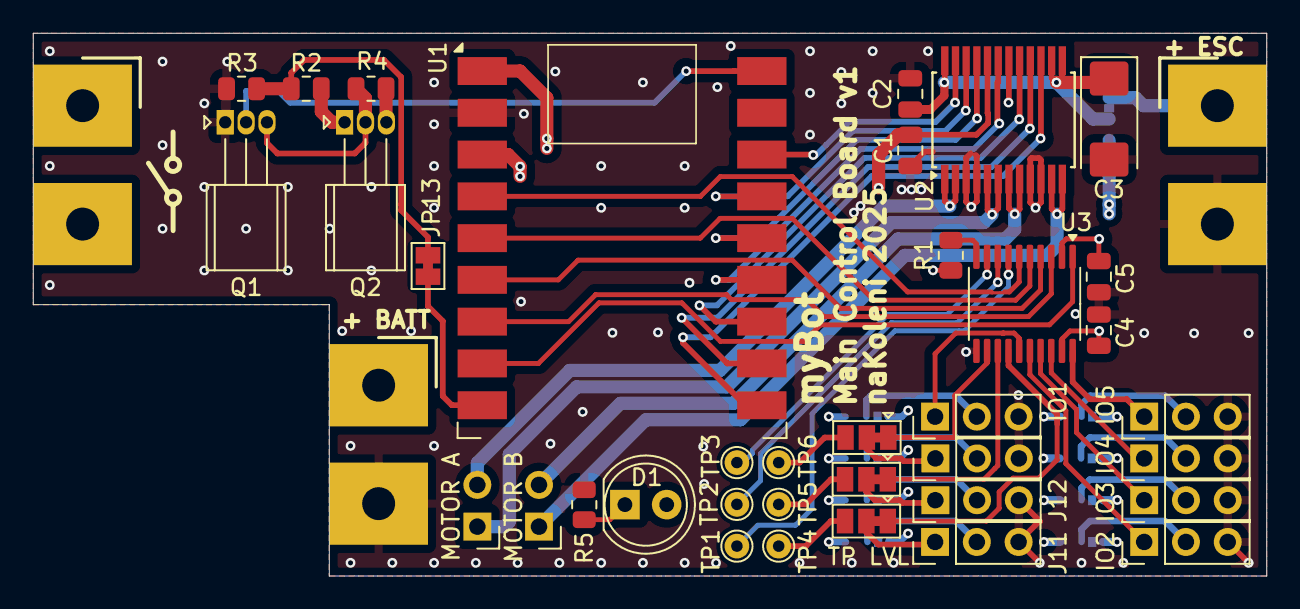
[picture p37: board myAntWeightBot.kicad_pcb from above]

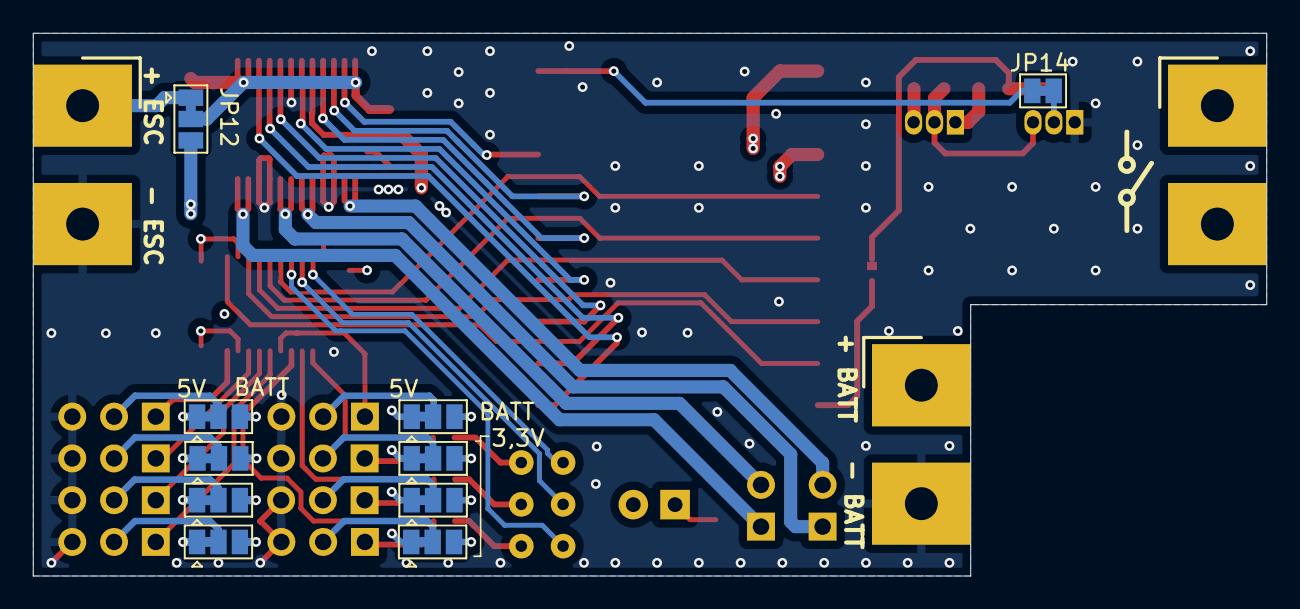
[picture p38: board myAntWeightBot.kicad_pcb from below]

Board: 4 copper layers, 75.0 x 33.0 mm, 49 parts (11 on the bottom side), 55 nets.

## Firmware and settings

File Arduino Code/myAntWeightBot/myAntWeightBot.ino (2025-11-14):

#include <Bluepad32.h>
#include <math.h>
#include <ESP32Servo.h>


#define BOT_MAX_GAMEPADS 1 
#define MIN_PROPULSION_SPEED 0
#define MAX_PROPULSION_SPEED 254
#define MIN_PROPULSION_SPEED_MARGIN 30
#define MAX_GAMEPAD_SPEED 512
#define SCALE_FACTOR MAX_PROPULSION_SPEED/MAX_GAMEPAD_SPEED  // Scale down the input range from [-512, 512] to [-255, 255] for motor control

#define LEFT_MOTOR_CTR_PIN_1 1
#define LEFT_MOTOR_CTR_PIN_2 2
#define RIGHT_MOTOR_CTR_PIN_1 3
#define RIGHT_MOTOR_CTR_PIN_2 4
#define WEAPON_MOTOR_CTR_PIN 6
#define SERVO_CTR_PIN 5

// Create a Servo object to control the ESC and servo
Servo esc;
Servo myServo;

int disabled = 1;


#define PROPULSION_SMOOTHING_FACTOR 0.5

int axisY = 0;  // Forward and Bakward joystick movement
int axisX = 0;  // Left and Right joystick movement
int previousAxisY = 0;
int previousAxisX = 0;
int filteredAxisY = 0;
int filteredAxisX = 0;

int throttleRight = 0;
int throttleLeft = 0;

ControllerPtr myControllers[BOT_MAX_GAMEPADS];



/**
 * Exponential Smoothing
 * Function to filter input values.
 * 
 * @param[in] currentDataSample .
 * @param[in] previousFilteredResult .
 * @param[in] alpha .
 * @param[out] limitedSpeed Speed limited into valid range.
 *
 */
int exponentialSmoothing(int currentDataSample, int previousFilteredResult, float alpha) {
  // Apply exponential smoothing formula
  float filtered = alpha * currentDataSample + (1.0 - alpha) * previousFilteredResult;
  return (int)filtered;
}

/**
 * Smooth Gamepad
 * Function to filter input values.

 *
 */
void smoothGamepad(void) {
  // Apply exponential smoothing formula

  // Smooth Y axis gamepad
  filteredAxisY = exponentialSmoothing(axisY,previousAxisY, PROPULSION_SMOOTHING_FACTOR);
  // Smooth X axis gamepad
  filteredAxisX = exponentialSmoothing(axisX,previousAxisX, PROPULSION_SMOOTHING_FACTOR);

  previousAxisY = filteredAxisY;
  previousAxisX = filteredAxisX;


}



/**
 * Limit Speed
 * Function to limit calculated motor speed to correct range.
 * 
 * @param[in] speed Calculated speed of rotation.
 * @param[out] limitedSpeed Speed limited into valid range.
 *
 */
uint8_t limitSpeed(float inputSpeed) {
  uint8_t limitedSpeed = 0;
  if (inputSpeed <= MIN_PROPULSION_SPEED + MIN_PROPULSION_SPEED_MARGIN)
  {
    limitedSpeed = MIN_PROPULSION_SPEED;
  }
  else if (inputSpeed >= MAX_PROPULSION_SPEED)
  {
    limitedSpeed = MAX_PROPULSION_SPEED;
  }
  else
  {
    limitedSpeed = (int)inputSpeed;
  }
  return limitedSpeed;
}

/**
 * Move Motor
 * Function to move a motor with defined speed and direction using TC1508A module with two control inputs per controled motor.
 * 
 * @param[in] ctrPin1 Control output pin of the ESP32 board connected to INT1.
 * @param[in] ctrPin2 Control output pin of the ESP32 board connected to INT2.
 * @param[in] speed Calculated speed of rotation.
 *
 */
void moveMotor(uint8_t ctrPin1, uint8_t ctrPin2, float speed)
{
  uint8_t speedToSet = 0;

  // Limit calculated speed value
  speedToSet = limitSpeed(fabs(speed));

  // Get direction 
  if (speed > 0)
  {
    // Forward
    analogWrite(ctrPin1, speedToSet);
    digitalWrite(ctrPin2, LOW);

    Serial.print(speedToSet);
    Serial.print(",");
  } else if (speed < 0)
  {
    // Backward
    digitalWrite(ctrPin1, LOW);
    analogWrite(ctrPin2, speedToSet);

    Serial.print(speedToSet*(-1));
    Serial.print(",");
  } else
  {
    // Backward
    digitalWrite(ctrPin1, LOW);
    digitalWrite(ctrPin2, LOW);

    Serial.print(0);
    Serial.print(",");
  }
  
}

/**
 * Move Robot
 * Function to move robot based on commands from gamepad.
 * 
 * @param[in] _axisX Gamepad controller input. Left and Right joystick movement.
 * @param[in] _axisY Gamepad controller input. Forward and Bakward joystick movement.
 *
 */
void moveRobot(int _axisX, int _axisY) 
{
  // Mix Y-axis (forward/reverse) and X-axis (turning/rotation)
  float right_speed = -((_axisY + _axisX) * SCALE_FACTOR);
  float left_speed = ((_axisY - _axisX) * SCALE_FACTOR);

  //Serial.print("left_speed:");
  //Serial.print(left_speed);
  //Serial.print(",");
  //Serial.print("right_speed:");
  //Serial.print(right_speed);
  //Serial.print(",");

  //Serial.print("left_speed_to_set:");
  moveMotor(LEFT_MOTOR_CTR_PIN_1, LEFT_MOTOR_CTR_PIN_2, left_speed);
  //Serial.print("right_speed_to_set:");
  moveMotor(RIGHT_MOTOR_CTR_PIN_1, RIGHT_MOTOR_CTR_PIN_2, right_speed);
}

/**
 * Collect Controller
 * Function to collect gamepad status into global variables.
 * 
 * @param[in] ctl Gamepad controller input.
 *
 */
void collectController(ControllerPtr ctl) 
{
  axisY = ctl->axisY();  // Forward and Bakward joystick movement
  axisX = ctl->axisRX();  // Left and Right joystick movement
  throttleRight = ctl->throttle();
  throttleLeft = ctl->brake();

}

// This callback gets called any time a new gamepad is connected.
// Up to 4 gamepads can be connected at the same time.
void onConnectedController(ControllerPtr ctl) {
    bool foundEmptySlot = false;
    for (int i = 0; i < BOT_MAX_GAMEPADS; i++) {
        if (myControllers[i] == nullptr) {
            Serial.printf("CALLBACK: Controller is connected, index=%d\n", i);
            // Additionally, you can get certain gamepad properties like:
            // Model, VID, PID, BTAddr, flags, etc.
            ControllerProperties properties = ctl->getProperties();
            Serial.printf("Controller model: %s, VID=0x%04x, PID=0x%04x\n", ctl->getModelName().c_str(), properties.vendor_id,
                           properties.product_id);
            myControllers[i] = ctl;
            foundEmptySlot = true;
            break;
        }
    }
    if (!foundEmptySlot) {
        Serial.println("CALLBACK: Controller connected, but could not found empty slot");
    }
}

void onDisconnectedController(ControllerPtr ctl) {
    bool foundController = false;
    disabled = 0;

    for (int i = 0; i < BOT_MAX_GAMEPADS; i++) {
        if (myControllers[i] == ctl) {
            Serial.printf("CALLBACK: Controller disconnected from index=%d\n", i);
            myControllers[i] = nullptr;
            foundController = true;
            break;
        }
    }

    if (!foundController) {
        Serial.println("CALLBACK: Controller disconnected, but not found in myControllers");
    }
}

void dumpGamepad(ControllerPtr ctl) {
    Serial.printf(
        "idx=%d, dpad: 0x%02x, buttons: 0x%04x, axis L: %4d, %4d, axis R: %4d, %4d, brake: %4d, throttle: %4d, "
        "misc: 0x%02x, gyro x:%6d y:%6d z:%6d, accel x:%6d y:%6d z:%6d\n",
        ctl->index(),        // Controller Index
        ctl->dpad(),         // D-pad
        ctl->buttons(),      // bitmask of pressed buttons
        ctl->axisX(),        // (-511 - 512) left X Axis
        ctl->axisY(),        // (-511 - 512) left Y axis
        ctl->axisRX(),       // (-511 - 512) right X axis
        ctl->axisRY(),       // (-511 - 512) right Y axis
        ctl->brake(),        // (0 - 1023): brake button
        ctl->throttle(),     // (0 - 1023): throttle (AKA gas) button
        ctl->miscButtons(),  // bitmask of pressed "misc" buttons
        ctl->gyroX(),        // Gyro X
        ctl->gyroY(),        // Gyro Y
        ctl->gyroZ(),        // Gyro Z
        ctl->accelX(),       // Accelerometer X
        ctl->accelY(),       // Accelerometer Y
        ctl->accelZ()        // Accelerometer Z
    );
}

void plotGamepad(ControllerPtr ctl) {
  //ctl->axisX(),        // (-511 - 512) left X Axis
  //      ctl->axisY(),        // (-511 - 512) left Y axis
  
  Serial.print("throttle_right:");
  Serial.print(ctl->throttle());
  Serial.print("throttle_left:");
  Serial.print(ctl->brake());
  Serial.print("Move_x:");
  Serial.print(ctl->axisX());
  Serial.print(",");
  Serial.print("Move_y:");
  Serial.println(ctl->axisY());
}



void processGamepad(ControllerPtr ctl) {
    // There are different ways to query whether a button is pressed.
    // By query each button individually:
    //  a(), b(), x(), y(), l1(), etc...
    if (ctl->a()) {
        static int colorIdx = 0;
        // Some gamepads like DS4 and DualSense support changing the color LED.
        // It is possible to change it by calling:
        switch (colorIdx % 3) {
            case 0:
                // Red
                ctl->setColorLED(255, 0, 0);
                break;
            case 1:
                // Green
                ctl->setColorLED(0, 255, 0);
                break;
            case 2:
                // Blue
                ctl->setColorLED(0, 0, 255);
                break;
        }
        colorIdx++;
    }

    if (ctl->b()) {
        // Turn on the 4 LED. Each bit represents one LED.
        static int led = 0;
        led++;
        // Some gamepads like the DS3, DualSense, Nintendo Wii, Nintendo Switch
        // support changing the "Player LEDs": those 4 LEDs that usually indicate
        // the "gamepad seat".
        // It is possible to change them by calling:
        ctl->setPlayerLEDs(led & 0x0f);
    }

    if (ctl->x()) {
        // Some gamepads like DS3, DS4, DualSense, Switch, Xbox One S, Stadia support rumble.
        // It is possible to set it by calling:
        // Some controllers have two motors: "strong motor", "weak motor".
        // It is possible to control them independently.
        ctl->playDualRumble(0 /* delayedStartMs */, 250 /* durationMs */, 0x80 /* weakMagnitude */,
                            0x40 /* strongMagnitude */);
    }

    // Another way to query controller data is by getting the buttons() function.
    // See how the different "dump*" functions dump the Controller info.
    // dumpGamepad(ctl);
    collectController(ctl); 
    plotGamepad(ctl);
}


void processControllers() {
    for (auto myController : myControllers) {
        if (myController && myController->isConnected() && myController->hasData()) {
            if (myController->isGamepad()) {
                processGamepad(myController);
            } else {
                Serial.println("Unsupported controller");
            }
        }
    }
}

// Function to set the throttle of the ESC (0 to 1024)
void setThrottle(int throttlePercentage) {
  int pulseWidth = map(throttlePercentage, 0, 1024, 1000, 2000);  // Map percentage to pulse width
  esc.writeMicroseconds(pulseWidth);  // Set ESC pulse width
}

// Function to set the servo position based on analog input (0 to 1023)
void setServoPosition(int analogValue) {
  int angle = map(analogValue, 0, 1023, 0, 180);
  // Move the servo to the corresponding angle
  myServo.write(angle);
}

// Arduino setup function. Runs in CPU 1
void setup() {

  // Propulsion motor output control pins setup
  pinMode(LEFT_MOTOR_CTR_PIN_1, OUTPUT);
  pinMode(LEFT_MOTOR_CTR_PIN_2, OUTPUT);
  pinMode(RIGHT_MOTOR_CTR_PIN_1, OUTPUT);
  pinMode(RIGHT_MOTOR_CTR_PIN_2, OUTPUT);

  // ESC Electronic Speed COntroller
  // Attach the ESC to the pin (50Hz for ESCs)
  esc.attach(WEAPON_MOTOR_CTR_PIN, 1000, 2000);  // min and max pulse width in microseconds (1ms to 2ms)
  
  // Start the ESC with minimum throttle to arm it
  setThrottle(0);  // 0% throttle
  delay(3000);     // Wait 3 seconds to let the ESC arm

  // Attach the servo to the pin (with default range of 0° to 180°)
  myServo.attach(SERVO_CTR_PIN);

  // Move the servo to the initial position (90°)
  myServo.write(90);  // Set to middle position
  delay(1000);  // Wait for the servo to move


  

  // Debug Serial interface setup
  Serial.begin(115200);
  Serial.printf("Firmware: %s\n", BP32.firmwareVersion());
  const uint8_t* addr = BP32.localBdAddress();
  Serial.printf("BD Addr: %2X:%2X:%2X:%2X:%2X:%2X\n", addr[0], addr[1], addr[2], addr[3], addr[4], addr[5]);

  // Setup the Bluepad32 callbacks
  BP32.setup(&onConnectedController, &onDisconnectedController);

  // "forgetBluetoothKeys()" should be called when the user performs
  // a "device factory reset", or similar.
  // Calling "forgetBluetoothKeys" in setup() just as an example.
  // Forgetting Bluetooth keys prevents "paired" gamepads to reconnect.
  // But it might also fix some connection / re-connection issues.
  BP32.forgetBluetoothKeys();

  // Enables mouse / touchpad support for gamepads that support them.
  // When enabled, controllers like DualSense and DualShock4 generate two connected devices:
  // - First one: the gamepad
  // - Second one, which is a "virtual device", is a mouse.
  // By default, it is disabled.
  BP32.enableVirtualDevice(false);
}

// Arduino loop function. Runs in CPU 1.
void loop() {
  // This call fetches all the controllers' data.
  // Call this function in your main loop.
  bool dataUpdated = BP32.update();
  if (dataUpdated)
    processControllers();
  smoothGamepad();
  moveRobot(filteredAxisX, filteredAxisY);
  setThrottle(throttleRight);
  setServoPosition(throttleLeft);
  if (disabled == 0)
  {
    
    while(true)
    {
      moveRobot(0, 0);
      setThrottle(0);
      Serial.print("disabled");
    }
  }


  // The main loop must have some kind of "yield to lower priority task" event.
  // Otherwise, the watchdog will get triggered.
  // If your main loop doesn't have one, just add a simple `vTaskDelay(1)`.
  // Detailed info here:
  // https://stackoverflow.com/questions/66278271/task-watchdog-got-triggered-the-tasks-did-not-reset-the-watchdog-in-time

  //     vTaskDelay(1);
  delay(150);
}

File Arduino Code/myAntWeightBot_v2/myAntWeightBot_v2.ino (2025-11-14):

#include <Bluepad32.h>            // BT gamepad control 
#include <math.h>                 // Math functions i.e. for smoothing filter
#include <ESP32Servo.h>           // Servo and ESC (brushless motor) control
#include <SparkFun_TB6612.h>      // DC motor control

#define SW_VERSION "v2.0.0"

// Configuration
#define BOT_MAX_GAMEPADS 1 
#define MIN_PROPULSION_SPEED -255
#define MAX_PROPULSION_SPEED 255
#define MIN_PROPULSION_SPEED_MARGIN 50
#define MIN_GAMEPAD_SPEED -512
#define MAX_GAMEPAD_SPEED 512
#define GAMEPAD_ZERO_POSITION_ERROR_MAX 40
#define PROPULSION_SMOOTHING_FACTOR 0.5
#define ESC_WEAPON_MIN_PULSE_WIDTH_US 1000        // Min pulse width in microseconds (1ms)
#define ESC_WEAPON_STOP_PULSE_WIDTH_US 1500  // Mid pulse width (to stop) in microseconds (1ms)
#define ESC_WEAPON_MAX_PULSE_WIDTH_US 2000        // Max pulse width in microseconds (2ms)
#define MOTOR_A_DIRECTION 1  // Value can be 1 or -1
#define MOTOR_B_DIRECTION 1  // Value can be 1 or -1

// GPIO PIN definition
#define MOTOR_AIN1 11  // modra ok
#define MOTOR_BIN1 9  // seda ok
#define MOTOR_AIN2 12  // zelena ok
#define MOTOR_BIN2 8  // bila ok
#define MOTOR_PWMA 13  // oranzova ok
#define MOTOR_PWMB 7  // hneda ok
#define MOTOR_STBY 10  // fialova ok
#define WEAPON_MOTOR_CTR_PIN 5
#define SERVO_CTR_PIN 3

// Global variables
bool gamepadDisconnected = false;
int axisY = 0;  // Forward and Bakward joystick movement
int axisX = 0;  // Left and Right joystick movement
int throttleRight = 0;
int throttleLeft = 0;
int previousAxisY = 0;
int previousAxisX = 0;
int filteredAxisY = 0;
int filteredAxisX = 0;
int speedMotorA = 0;
int speedMotorB = 0;

// Objects
Servo escWeapon;        // ESC (Electronic Speed Controller) for weapon motor 
Servo myServo;          // Servo motor for arm
Motor motorA = Motor(MOTOR_AIN1, MOTOR_AIN2, MOTOR_PWMA, MOTOR_A_DIRECTION, MOTOR_STBY);
Motor motorB = Motor(MOTOR_BIN1, MOTOR_BIN2, MOTOR_PWMB, MOTOR_B_DIRECTION, MOTOR_STBY);
ControllerPtr myControllers[BOT_MAX_GAMEPADS];

/**
 * Exponential Smoothing
 * Function to filter input values.
 * 
 * @param[in] currentDataSample
 * @param[in] previousFilteredResult
 * @param[in] alpha
 *
 */
int exponentialSmoothing(int currentDataSample, int previousFilteredResult, float alpha) {
  // Apply exponential smoothing formula
  float filtered = alpha * currentDataSample + (1.0 - alpha) * previousFilteredResult;
  return (int)filtered;
}

/**
 * Smooth Gamepad
 * Function to filter Gamepad values.
 * @param[in] _axisY Raw (unfiltered) axis Y value.
 * @param[in] _axisX Raw (unfiltered) axis X value.
 * @param[in, out] _previousAxisY Previous filtered axis Y value.
 * @param[in, out] _previousAxisX Previous filtered axis X value.
 * @param[out] _filteredAxisY Filtered axis Y value.
 * @param[out] _filteredAxisX Filtered axis X value.
 *
 */
void smoothGamepad(int _axisY, 
                   int _axisX, 
                   int* _previousAxisY, 
                   int* _previousAxisX, 
                   int* _filteredAxisY, 
                   int* _filteredAxisX) {
  // Apply exponential smoothing formula

  // Smooth Y axis gamepad
  *_filteredAxisY = exponentialSmoothing(_axisY, *_previousAxisY, PROPULSION_SMOOTHING_FACTOR);
  // Smooth X axis gamepad
  *_filteredAxisX = exponentialSmoothing(_axisX, *_previousAxisX, PROPULSION_SMOOTHING_FACTOR);

  *_previousAxisY = *_filteredAxisY;
  *_previousAxisX = *_filteredAxisX;
}

/**
 * Calculate motor speed
 * Function to calculate X,Y gamepad inputs to speed of differential stearing motors.
 *
 * @param[in] _axisX Gamepad controller input. Left and Right joystick movement.
 * @param[in] _axisY Gamepad controller input. Forward and Bakward joystick movement.
 * @param[out] _speedA pointer to speed of motor A.
 * @param[out] _speedB pointer to speed of motor B.
 *
 */
void calculateMotorSpeed(int _axisX, int _axisY, int* _speedA, int* _speedB) 
{
  // Mix Y-axis (forward/reverse) and X-axis (turning/rotation)
  int _calculatedSpeedA = _axisY + _axisX;
  int _calculatedSpeedB = _axisY - _axisX;

  // Limit the calculated values to +-512
  // Needed when using two separate gamepad joysticks
  int _limitedSpeedA = constrain(_calculatedSpeedA, MIN_GAMEPAD_SPEED, MAX_GAMEPAD_SPEED);
  int _limitedSpeedB = constrain(_calculatedSpeedB, MIN_GAMEPAD_SPEED, MAX_GAMEPAD_SPEED);

  // Map the calculated speed values to speed values able to set
  *_speedA = map(_limitedSpeedA, MIN_GAMEPAD_SPEED, MAX_GAMEPAD_SPEED, MIN_PROPULSION_SPEED, MAX_PROPULSION_SPEED);
  *_speedB = map(_limitedSpeedB, MIN_GAMEPAD_SPEED, MAX_GAMEPAD_SPEED, MIN_PROPULSION_SPEED, MAX_PROPULSION_SPEED);
}

/**
 * Move Robot 
 * Function to move robot based on input speed.
 *
 * @param[in] _speedA Speed to set for motor A.
 * @param[in] _speedB Speed to set for motor B.
 *
 */
void moveRobot(int _speedA, int _speedB) 
{
  if (abs(_speedA) > MIN_PROPULSION_SPEED_MARGIN) {
    motorA.drive(_speedA);
    delay(1);  // Minimum delay
  } else {
    motorA.brake();
    delay(1);
  }

  if (abs(_speedB) > MIN_PROPULSION_SPEED_MARGIN) {
    motorB.drive(_speedB);
    delay(1);  // Minimum delay
  } else {
    motorB.brake();
    delay(1);
  }
}

/**
 * Collect Controller
 * Function to collect gamepad status into global variables.
 * 
 * @param[in] ctl Gamepad controller input.
 *
 */
void collectController(ControllerPtr ctl) 
{
  axisY = (ctl->axisY());  // Forward (positive) and Bakward (negative) joystick movement
  axisX = -(ctl->axisRX());  // Left (positive) and Right (negative) joystick movement
  throttleRight = ctl->throttle();
  throttleLeft = ctl->brake();

  if (abs(axisY) < GAMEPAD_ZERO_POSITION_ERROR_MAX) {
    axisY = 0;  // Limit gamepad joistick 0 position error
  }

  if (abs(axisX) < GAMEPAD_ZERO_POSITION_ERROR_MAX) {
    axisX = 0;  // Limit gamepad joistick 0 position error
  }
}

/**
 * On connected Controller
 * This callback gets called any time a new gamepad is connected.
 * 
 * @param[in] ctl Gamepad controller input.
 *
 */
void onConnectedController(ControllerPtr ctl) {
    bool foundEmptySlot = false;
    for (int i = 0; i < BOT_MAX_GAMEPADS; i++) {
        if (myControllers[i] == nullptr) {
            Serial.printf("CALLBACK: Controller is connected, index=%d\n", i);
            // Additionally, you can get certain gamepad properties like:
            // Model, VID, PID, BTAddr, flags, etc.
            ControllerProperties properties = ctl->getProperties();
            Serial.printf("Controller model: %s, VID=0x%04x, PID=0x%04x\n", ctl->getModelName().c_str(), properties.vendor_id,
                           properties.product_id);
            myControllers[i] = ctl;
            foundEmptySlot = true;
            break;
        }
    }
    if (!foundEmptySlot) {
        Serial.println("CALLBACK: Controller connected, but could not found empty slot");
    }
}
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

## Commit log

2024-09-10 working foundatiton tested with one motor
2025-11-14 all old
    [AMASS_XT60-F_1x02_P7.2mm_Vertical v2.step, AMASS_XT60-M_1x02_P7.2mm_Vertical v2.step, ArmCover Left v29.stl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]
2025-11-14 initial config
    [app3M_fat9M_16MB.csv, app3M_fat9M_fact512k_16MB.csv, app3M_spiffs9M_fact512k_16MB.csv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]
2025-11-15 battery meas and telemetry
